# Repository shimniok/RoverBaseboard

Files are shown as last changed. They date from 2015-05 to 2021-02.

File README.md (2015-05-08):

RoverBaseboard is a baseboard for use in autonomous rover projects. It supports mbed LPC1768, LPCXpresso,
and compatible pinouts. This same baseboard design was used on my 1986 Jeep Grand Wagoneer, "Troubled Child"
when it won 1st place, "Doping" class, in the 2014 Sparkfun AVC.

The baseboard breaks out UARTs, I2C, analog, digital, PWM. Each I2C and UART "port" also provides 5V, 3.3V, GND
pins.  It features a microSD card socket and an onboard 3.3V external LDO regulator.

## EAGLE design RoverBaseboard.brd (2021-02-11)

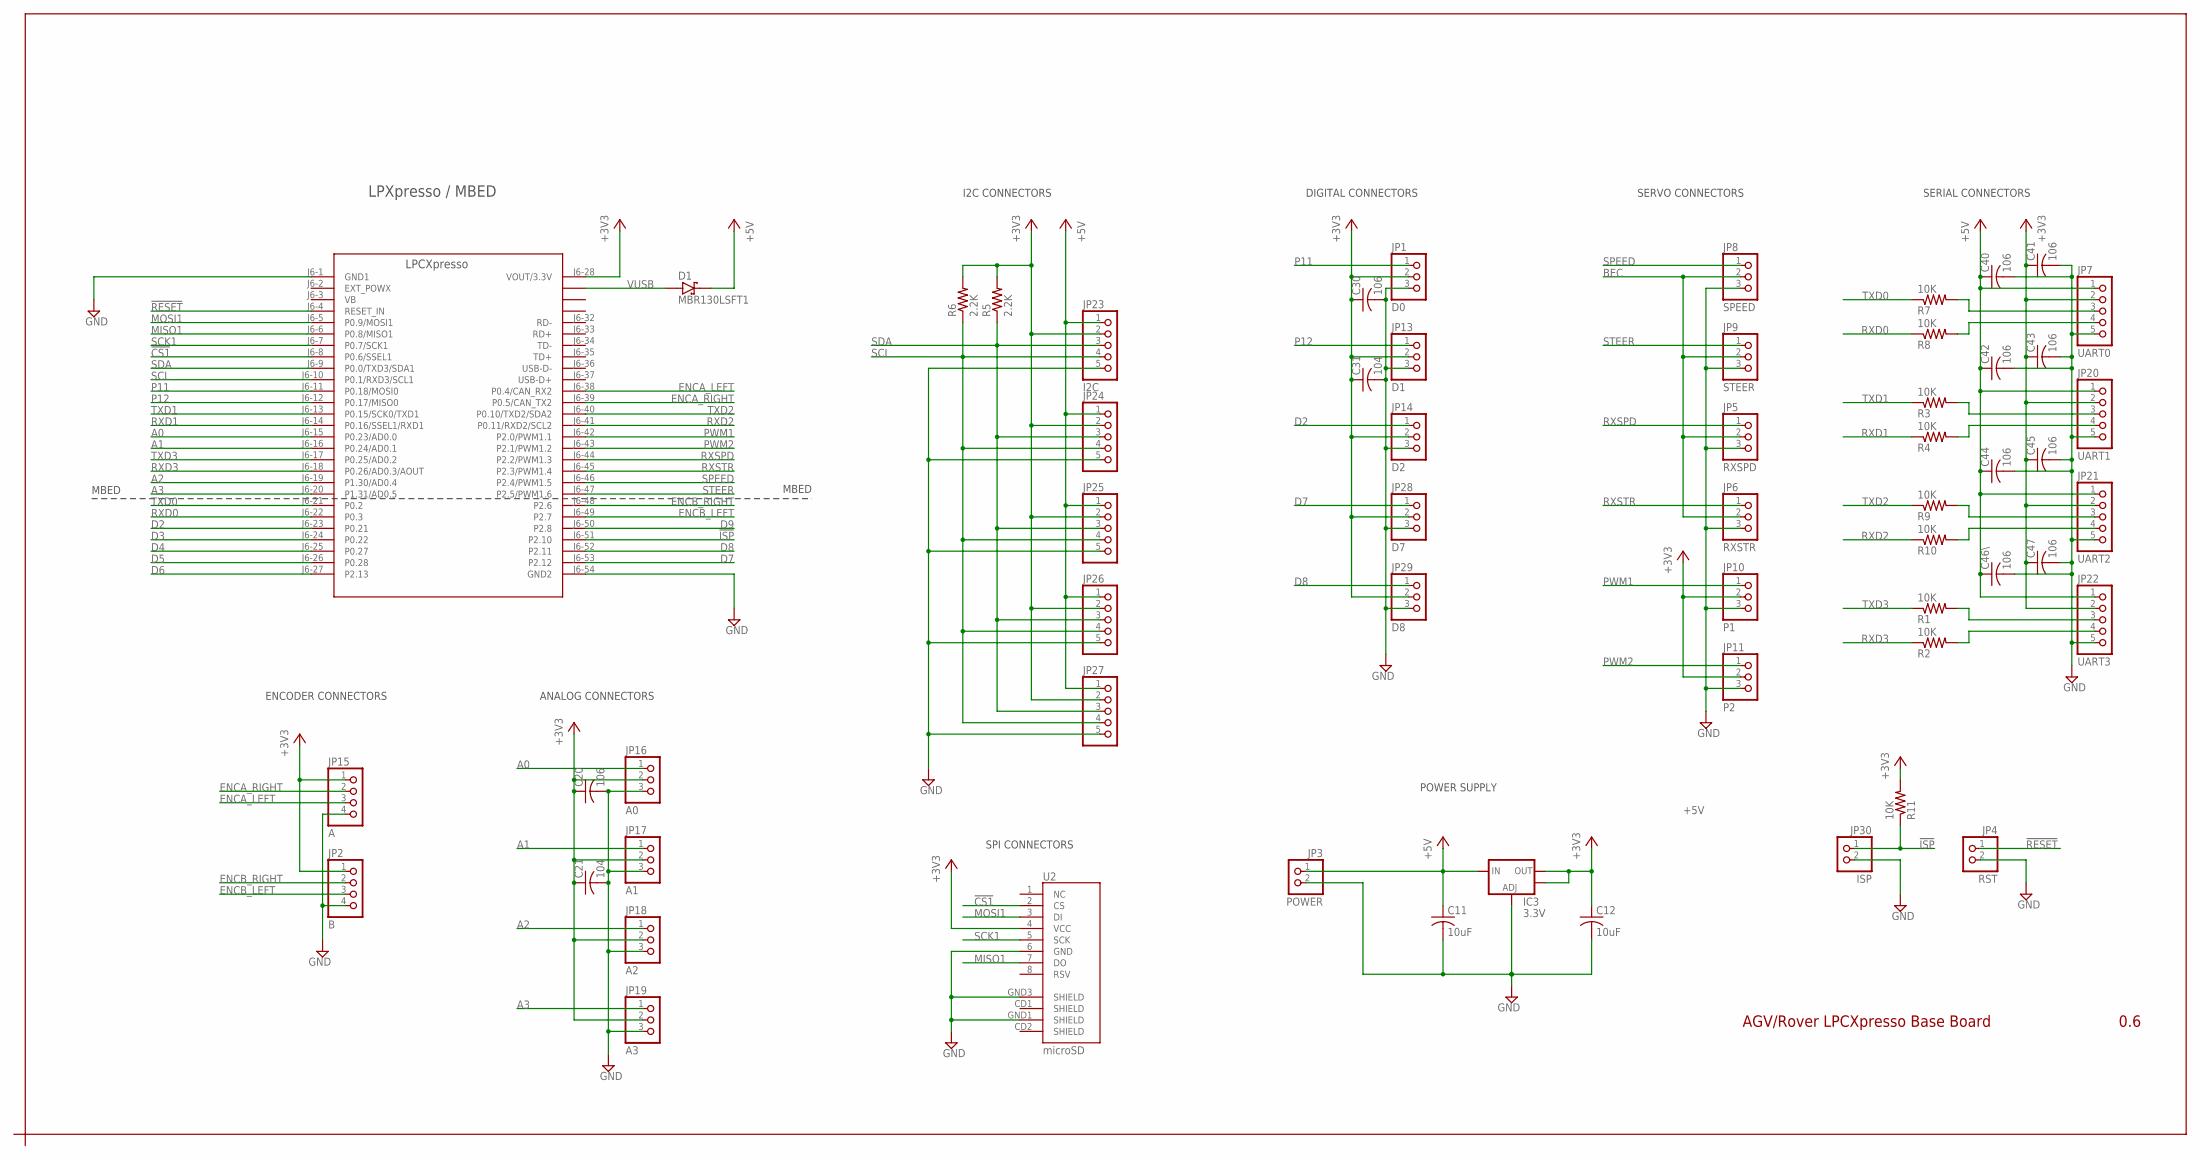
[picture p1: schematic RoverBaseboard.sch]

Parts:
C11, C12: 10uF; C1206
C20, C30, C40, C41, C42, C43, C44, C45, C46\, C47: 106; C0603
C21, C31: 104; C0603
D1: MBR130LSFT1; SOD123FL
IC3: 3.3V; SOT223
JP1: D0; 1X03-S
JP2: B; 1X04-S
JP3: POWER; 1X02-S
JP4: RST; 1X02-S
JP5: RXSPD; 1X03-S
JP6: RXSTR; 1X03-S
JP7: UART0; 1X05-S
JP8: SPEED; 1X03-S
JP9: STEER; 1X03-S
JP10: P1; 1X03-S
JP11: P2; 1X03-S
JP13: D1; 1X03-S
JP14: D2; 1X03-S
JP15: A; 1X04-S
JP16: A0; 1X03-S
JP17: A1; 1X03-S
JP18: A2; 1X03-S
JP19: A3; 1X03-S
JP20: UART1; 1X05-S
JP21: UART2; 1X05-S
JP22: UART3; 1X05-S
JP23: I2C; 1X05-S
JP24, JP25, JP26, JP27: PINHD-1X05_2.54-S; 1X05-S
JP28: D7; 1X03-S
JP29: D8; 1X03-S
JP30: ISP; 1X02-S
R1, R2, R3, R4, R7, R8, R9, R10, R11: 10K; R0603; MPN WCR0805-220RFI
R5, R6: 2.2K; R0603
U2: microSD; MICRO-SD-SOCKET-PP
U$1: LPCXPRESSO; LPCXPRESSO_NO_PAD

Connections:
!CS1: U2.2 (CS), U$1.J6-8 (P0.6/SSEL1)
!ISP: JP30.1, R11.1, U$1.J6-51 (P2.10)
!RESET: JP4.1, U$1.J6-4 (RESET_IN)
+3V3: C12.1, C20.1, C21.1, C30.1, C31.1, C41.1, C43.1, C45.1, C47.1, IC3.2 (OUT), IC3.4 (OUT), JP1.2, JP2.1, JP7.2, JP10.2, JP11.2, JP13.2, JP14.2, JP15.1, JP16.2, JP17.2, JP18.2, JP19.2, JP20.2, JP21.2, JP22.2, JP23.2, JP24.2, JP25.2, JP26.2, JP27.2, JP28.2, JP29.2, R5.2, R6.2, R11.2, U2.4 (VCC), U$1.J6-28 (VOUT/3.3V)
+5V: C11.1, C40.1, C42.1, C44.1, C46\.1, D1.C, IC3.3 (IN), JP3.1, JP7.1, JP20.1, JP21.1, JP22.1, JP23.1, JP24.1, JP25.1, JP26.1, JP27.1
A0: JP16.1, U$1.J6-15 (P0.23/AD0.0)
A1: JP17.1, U$1.J6-16 (P0.24/AD0.1)
A2: JP18.1, U$1.J6-19 (P1.30/AD0.4)
A3: JP19.1, U$1.J6-20 (P1.31/AD0.5)
BEC: JP5.2, JP6.2, JP8.2, JP9.2
D2: JP14.1, U$1.J6-23 (P0.21)
D3: U$1.J6-24 (P0.22)
D4: U$1.J6-25 (P0.27)
D5: U$1.J6-26 (P0.28)
D6: U$1.J6-27 (P2.13)
D7: JP28.1, U$1.J6-53 (P2.12)
D8: JP29.1, U$1.J6-52 (P2.11)
D9: U$1.J6-50 (P2.8)
ENCA_LEFT: JP15.3, U$1.J6-38 (P0.4/CAN_RX2)
ENCA_RIGHT: JP15.2, U$1.J6-39 (P0.5/CAN_TX2)
ENCB_LEFT: JP2.3, U$1.J6-49 (P2.7)
ENCB_RIGHT: JP2.2, U$1.J6-48 (P2.6)
GND: C11.2, C12.2, C20.2, C21.2, C30.2, C31.2, C40.2, C41.2, C42.2, C43.2, C44.2, C45.2, C46\.2, C47.2, IC3.1 (ADJ), JP1.3, JP2.4, JP3.2, JP4.2, JP5.3, JP6.3, JP7.5, JP8.3, JP9.3, JP10.3, JP11.3, JP13.3, JP14.3, JP15.4, JP16.3, JP17.3, JP18.3, JP19.3, JP20.5, JP21.5, JP22.5, JP23.5, JP24.5, JP25.5, JP26.5, JP27.5, JP28.3, JP29.3, JP30.2, U2.6 (GND), U2.GND1 (SHIELD), U2.GND3 (SHIELD), U$1.J6-1 (GND1), U$1.J6-54 (GND2)
MISO1: U2.7 (DO), U$1.J6-6 (P0.8/MISO1)
MOSI1: U2.3 (DI), U$1.J6-5 (P0.9/MOSI1)
unnamed: JP22.3, R1.2
unnamed: JP22.4, R2.2
unnamed: JP7.3, R7.2
unnamed: JP7.4, R8.2
unnamed: JP20.3, R3.2
unnamed: JP20.4, R4.2
unnamed: JP21.3, R9.2
unnamed: JP21.4, R10.2
P11: JP1.1, U$1.J6-11 (P0.18/MOSI0)
P12: JP13.1, U$1.J6-12 (P0.17/MISO0)
PWM1: JP10.1, U$1.J6-42 (P2.0/PWM1.1)
PWM2: JP11.1, U$1.J6-43 (P2.1/PWM1.2)
RXD0: R8.1, U$1.J6-22 (P0.3)
RXD1: R4.1, U$1.J6-14 (P0.16/SSEL1/RXD1)
RXD2: R10.1, U$1.J6-41 (P0.11/RXD2/SCL2)
RXD3: R2.1, U$1.J6-18 (P0.26/AD0.3/AOUT)
RXSPD: JP5.1, U$1.J6-44 (P2.2/PWM1.3)
RXSTR: JP6.1, U$1.J6-45 (P2.3/PWM1.4)
SCK1: U2.5 (SCK), U$1.J6-7 (P0.7/SCK1)
SCL: JP23.4, JP24.4, JP25.4, JP26.4, JP27.4, R6.1, U$1.J6-10 (P0.1/RXD3/SCL1)
SDA: JP23.3, JP24.3, JP25.3, JP26.3, JP27.3, R5.1, U$1.J6-9 (P0.0/TXD3/SDA1)
SPEED: JP8.1, U$1.J6-46 (P2.4/PWM1.5)
STEER: JP9.1, U$1.J6-47 (P2.5/PWM1.6)
TXD0: R7.1, U$1.J6-21 (P0.2)
TXD1: R3.1, U$1.J6-13 (P0.15/SCK0/TXD1)
TXD2: R9.1, U$1.J6-40 (P0.10/TXD2/SDA2)
TXD3: R1.1, U$1.J6-17 (P0.25/AD0.2)
VUSB: D1.A, U$1.J6-31

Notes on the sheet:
SERVO CONNECTORS
SPI CONNECTORS
I2C CONNECTORS
SERIAL CONNECTORS
AGV/Rover LPCXpresso Base Board
0.6
ANALOG CONNECTORS
DIGITAL CONNECTORS
MBED
ENCODER CONNECTORS
LPXpresso / MBED
POWER SUPPLY

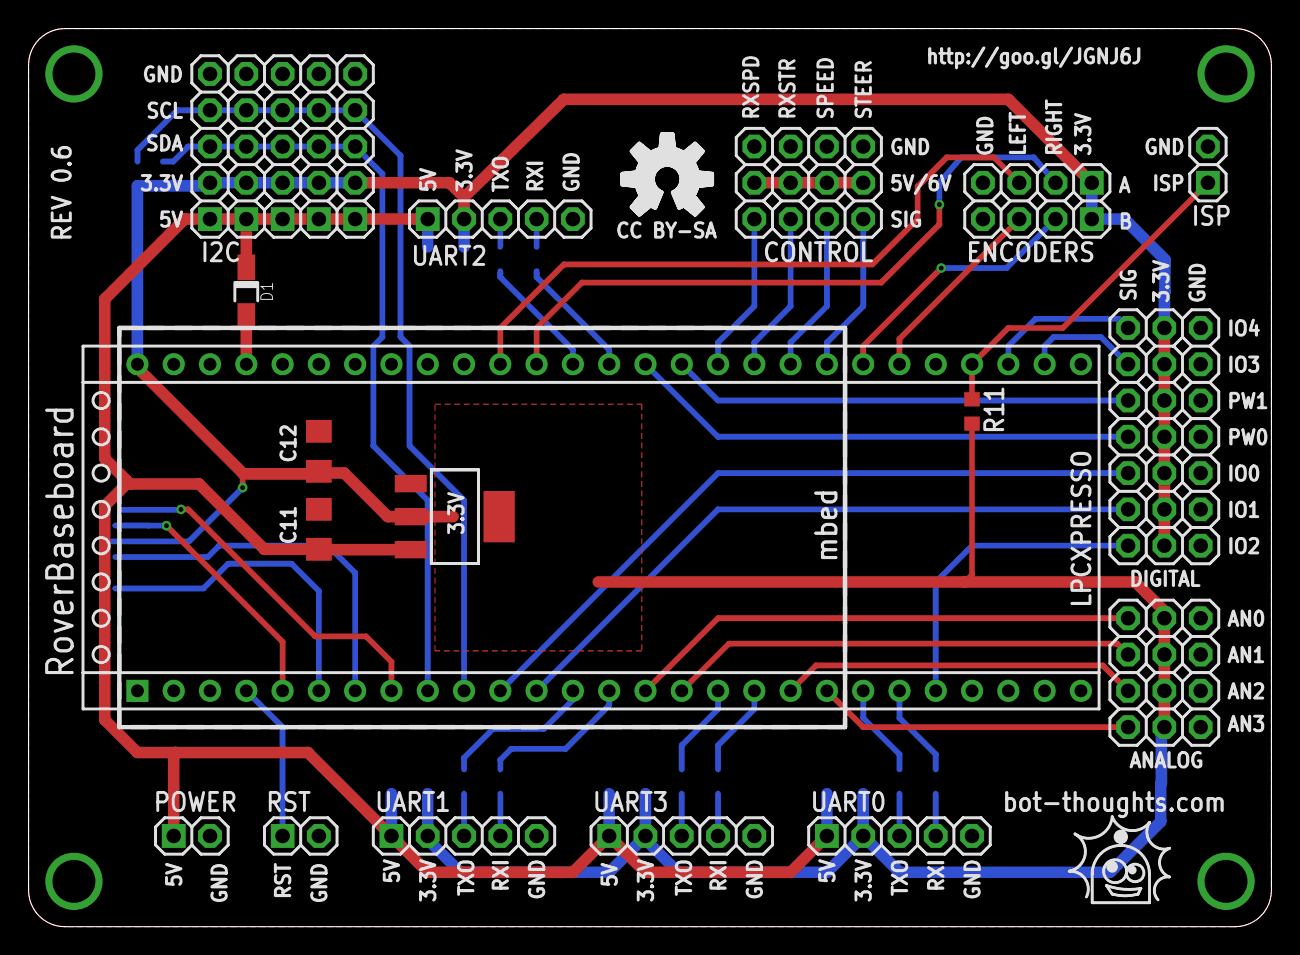
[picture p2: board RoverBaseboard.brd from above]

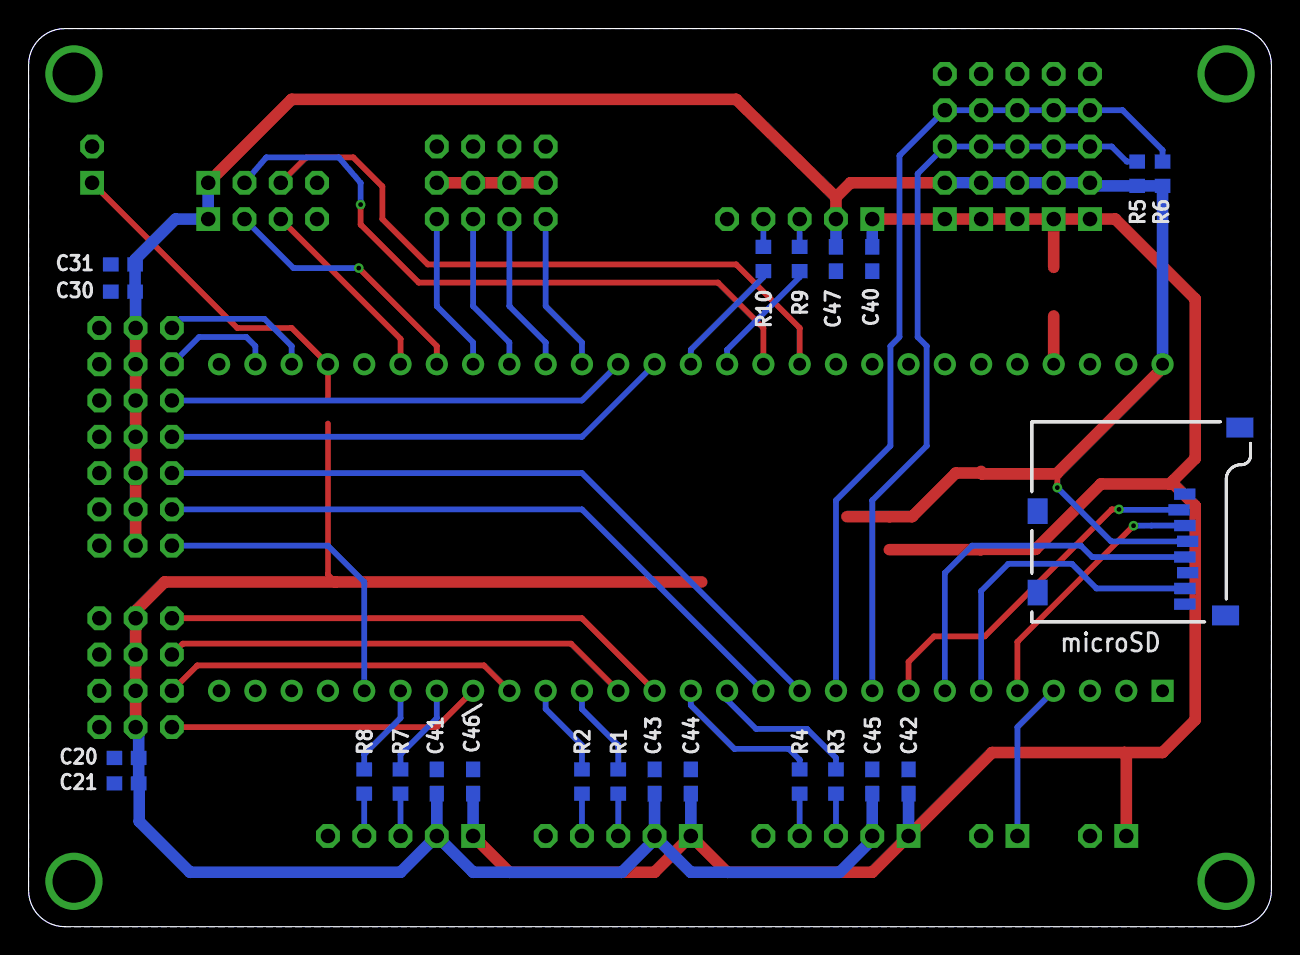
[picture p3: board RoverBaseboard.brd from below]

Board: 2 copper layers, 87.0 x 62.9 mm, 58 parts (23 on the bottom side), 48 nets.

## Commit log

2013-11-04 Trying to fix repository
    [5V ADC mbed.brd, 5V ADC mbed.sch, AVRcamMount.skp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]
2013-11-05 Bugfix to supply--3.3V regulator now feeds LPCXpresso. Minor tweaks. Powering analog ports more directly. Rerouted power. Moved power pins to align to 0.1" spacing. Heat sink now connected to 3V3 out.
    [RoverBaseboard.brd, RoverBaseboard.sch]
2013-11-22 Change to LDO regulator, added port labels for digital, analog, encoders, change cap values.
    [RoverBaseboard.brd, RoverBaseboard.sch]
2013-11-22 Renamed VBEC net
    [RoverBaseboard.brd, RoverBaseboard.sch]
2013-11-22 Added ISP pushbutton and pullup
    [RoverBaseboard.brd, RoverBaseboard.sch]
2014-02-04 Added ISP pin headers, revised power supply selection layout, added pin header for selecting external 5VIN in addition to selections for 5V or 6V BEC. Renumbered capacitors. Verified cap voltages, et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
    [RoverBaseboard.brd, RoverBaseboard.sch]
2014-02-04 Added documentation to schematic
    [RoverBaseboard.brd, RoverBaseboard.sch]
2014-03-11 Revised net names to better reflect encoders. Changed pin header labels to better reflect function.
    [RoverBaseboard.brd, RoverBaseboard.sch]
2014-05-16 Updated pin names, removed BEC>5V regulator, moved VIN pins back to original spot.
    [RoverBaseboard.brd, RoverBaseboard.sch]
2014-05-16 Added gerber files and zip
    [RoverBaseboard.drills.xln]
2021-02-11 added diode for VUSB/5V so both can be connected safely
    [RoverBaseboard.brd, RoverBaseboard.sch]

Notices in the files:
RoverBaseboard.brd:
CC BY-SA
